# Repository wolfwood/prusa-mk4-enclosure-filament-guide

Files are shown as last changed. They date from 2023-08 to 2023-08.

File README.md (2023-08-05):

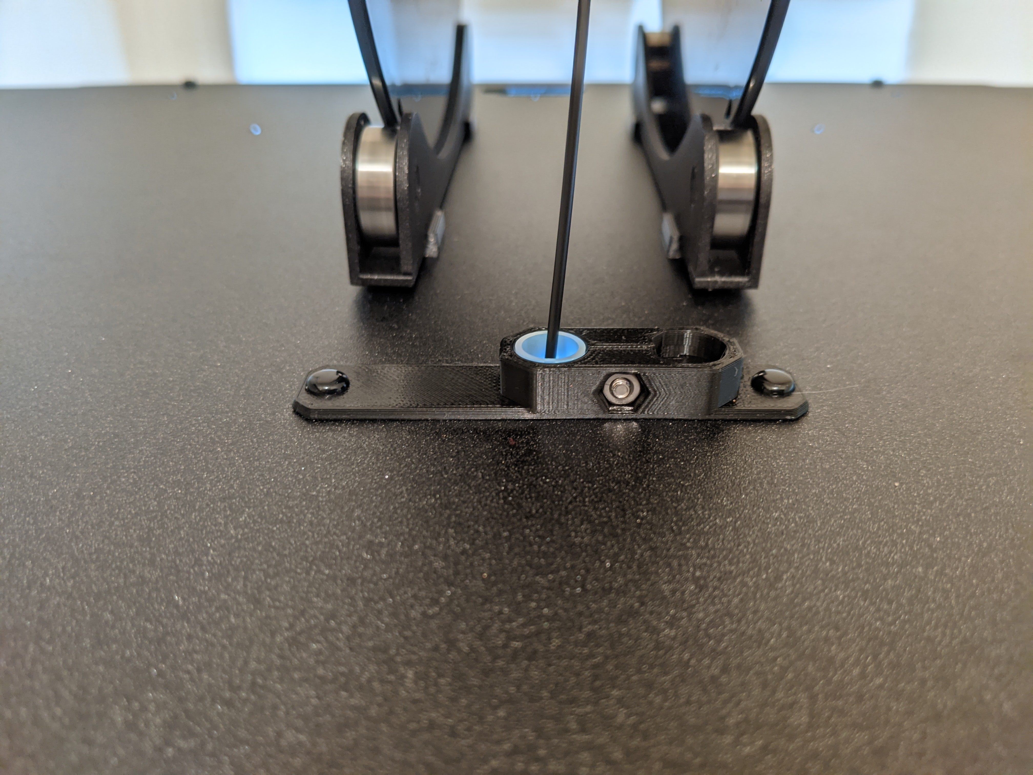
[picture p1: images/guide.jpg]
the guide in use on top of the prusa enclosure, with a spool roller


For printing TPU on the MK4, with the load cell, I wanted the filament path to be as smooth and straight as possible. I plan to use a roller bearing spool holder on top of my Prusa Enclosure and to skip the bowden tube.

This model accepts the filament guide PTFE tube from the MK4 and secures it using a M3 screw and nut, same as the original.

This print uses the following parts from one side of the filament guide (leaving the other side intact for continued use with the lid open, or on another printer):

  * Filament guide PTFE tube (1x)
  * M3n nut (1x)
  * M3x10 screw (1x)
  * Nylon rivet (2x)

[Assembly instructions match those of the filament guide](https://help.prusa3d.com/guide/7-y-carriage-heatbed-assembly_438310#440120).

Pregenerated STLs can be found in the Releases tab for this project. The *enclosure-top-filament-guide.stl* version prints as-is, but does not plug the top center hole, only covers it. The *enclosure-top-filament-guide-needs-supports.stl* retains most of the plug but must be printed with (organic) supports.

The guide/cover is held in place by nylon rivets, [as shown in the enclosure assembly guide](https://help.prusa3d.com/guide/6-hinged-lid-add-on_354154#354289).

This is a remix of [the Prusa MK4 filament guide](https://www.printables.com/model/434911-filament-guide) and the [Prusa Enclosure]() from Prusa, the source *.stl*s belong to them.

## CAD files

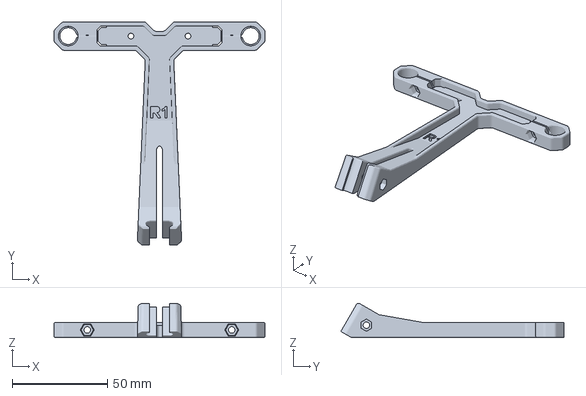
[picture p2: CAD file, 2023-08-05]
filament-guide-R1.3mf
111.0 x 117.5 x 17.9 mm

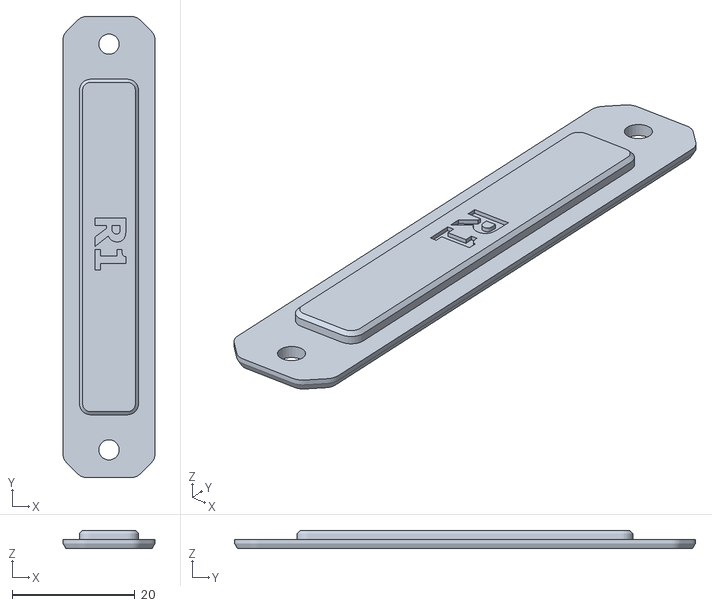
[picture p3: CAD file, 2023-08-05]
Top-plug-center.stl
15.0 x 75.0 x 3.00

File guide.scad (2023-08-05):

module prusa_plug() {
  rotate([180,0,90]) translate([0,0,-1.5])import("Top-plug-center.stl");
}

module prusa_guide() {
  translate([48.15,-51.25,8.9612]) difference(){
    import("filament-guide-R1.3mf");
    let(z=40) translate([-27.5,-60,-z/2]) cube([90,130,z]);
  }
}

module guide_end(){
  rotate([0,0,180]) difference() {
    prusa_guide();
    translate([20,0,0]) cube([40,20,20],center=true);
  }
}

module enclosure_top_filament_guide_flat(){
  difference(){
    prusa_plug();
    // remove material from plug that would block the holes in the bottom of the guide on the +X axis side
    //translate([0,-10,-2])cube([20.5,20,4]);
    let(y=11)translate([0,-y/2,-2])cube([20.5,y,4]);
    // don't block the screw holes in the sides
    let(y=16)translate([0,-y/2,.75])cube([20.5,y,4]);

    // remove the part that goes into the lid hole so we can print without supports
    *translate([-5-3,-10,-4])cube([20.5,20,4]);
    let(x=80)translate([-x/2,-10,-4])cube([x,20,4]);

    // cut the PTFE tube hole for the -X axis side of the hole
    cylinder($fn=60, r=5.5,h=4,center=true);
  }

  prusa_guide();

  translate([20.15,0,0]) {
    // extend the deck of the flex chamber
    let(x=5,y=11,z=4){
      difference(){
	translate([.5,-y/2,0])cube([x,y,z]);

	// remove protruding corners
	let(dx=5,dy=3) {
	  translate([dx,dy,-1]) rotate([0,0,45]) cube([3,3,z+2]);
	  mirror([0,-1,0])translate([dx,dy,-1]) rotate([0,0,45]) cube([3,3,z+2]);
	}
      }
    }

    // close the flex chamber keeping both inside and outside walls flush
    intersection(){
      scale([1,1.025,1]) guide_end();
      guide_end();
    }
  }
}

module enclosure_top_filament_guide(){
  difference(){
    prusa_plug();

    // extrude the flex cuts
    translate([0,0,-2]) linear_extrude(4) projection() difference() {
      let(x=22.5,y=14)translate([-2,-y/2,0])cube([x,y,.1]);
      translate([0,0,-2]) linear_extrude(4) projection() intersection(){
	let(x=80)translate([-x/2,-10,0])cube([x,20,.1]);
	prusa_guide();
      }
    }

    // don't block the screw holes in the sides
    let(y=16)translate([0,-y/2,.75])cube([20.5,y,4]);

    // cut the PTFE tube hole for the -X axis side of the hole
    cylinder($fn=120, r=6.9,h=4,center=true);
  }

  prusa_guide();

  translate([20.15,0,0]) {
    // extend the deck of the flex chamber
    let(x=5,y=11,z=4){
      difference(){
	translate([.5,-y/2,0])cube([x,y,z]);

	// remove protruding corners
	let(dx=5,dy=3) {
	  translate([dx,dy,-1]) rotate([0,0,45]) cube([3,3,z+2]);
	  mirror([0,-1,0])translate([dx,dy,-1]) rotate([0,0,45]) cube([3,3,z+2]);
	}
      }
    }

    // close the flex chamber keeping both inside and outside walls flush
    intersection(){
      scale([1,1.025,1]) guide_end();
      guide_end();
    }
  }
}

enclosure_top_filament_guide();

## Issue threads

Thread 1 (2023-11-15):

Final STL file missing

christoph-buente, 2023-11-15:
Hey James, thanks for the great idea of the remix of the filament guide and the top cover. On the foto it shows the final file, but this GitHub repo does not seem to have the actual STL file for it. Where would i be able to get this file? Thanks again, appreciate the work!

christoph-buente, 2023-11-15:
Nevermind, found the result in the github releases!

Closed 2023-11-15.

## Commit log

2023-08-05 source parts from Prusa enclosure and Prusa MK4
    [Top-plug-center.stl, filament-guide-R1.3mf]
2023-08-05 code for the filament guide
    [guide.scad]
